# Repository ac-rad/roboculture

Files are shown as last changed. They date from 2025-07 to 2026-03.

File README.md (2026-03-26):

# RoboCulture



This repository accompanies the paper:

**RoboCulture: A Robotics Platform for Automated Biological Experimentation**  
Paper: https://arxiv.org/abs/2505.14941
Project website: https://ac-rad.github.io/roboculture

**RoboCulture** is a cost-effective and flexible platform
that uses a general-purpose robotic manipulator to automate
key biological tasks. RoboCulture performs liquid handling, interacts with lab equipment, and leverages computer vision
for real-time decisions using optical density-based growth
monitoring. 

This repository contains instructions to replicate our fully autonomous 15-hour yeast culture experiment where RoboCulture uses vision and force feedback and a modular behavior tree framework to robustly execute, monitor, and manage experiments.

## Repository Structure

```
roboculture/
├── digital-pipette-v2/    # Digital Pipette v2 hardware + software
├── cad-models/            # 3D-printable CAD assets for the yeast culture experiment
├── src/                   # ROS nodes and experiment code
│   ├── calibrate_camera.py              # Camera intrinsic calibration script
│   ├── process_well_data.py             # Generates growth curve plots from experiment CSVs
│   ├── camera_cal_imgs/             # Chessboard calibration images and calibration.npz
│   └── cell_culture/                # ROS package for the cell culture experiment
│       ├── action/                  # ROS action definitions (control, perception, imaging)
│       ├── cfg/                     # Dynamic reconfigure config files
│       ├── config/                  # ROS launch file and parameter config (config.yaml)
│       ├── msg/                     # ROS message definitions (PlateGrowthMsg)
│       └── src/                     # Python source code
│           ├── cc_control_node.py           # ROS node: robot motion and gripper control
│           ├── cc_perception_node.py        # ROS node: vision, AprilTag, well detection
│           ├── cell_culture_global_reconfigure.py  # Dynamic reconfigure server
│           ├── device_controller.py         # Serial device control (pipette, shaker)
│           ├── behaviour-tree/              # Behavior tree definitions for each experiment stage
│           ├── behaviour/                   # Individual behavior node implementations
│           ├── helpers/                     # Shared utilities
│           │   └── process_well_image.py    # Captures well images and logs HSV data to CSV
│           └── tools/
│               └── april_tag_offset_calibrator.py  # AprilTag pose offset calibration tool
├── data/                  # Experiment output (auto-created at runtime)
├── static/                # Project website files
├── FastSAM/               # FastSAM submodule
└── readme-imgs/           # Images used in this README
```

## Hardware and Materials

**Required Hardware and Scene Setup**
1. Digital Pipette v2  
   - Follow instructions in [`digital-pipette-v2/`](digital-pipette-v2/) to build the pipette
    - Connect Arduino to the workstation via USB-B
    - Connect the 6 V power supply
    - Attach the Digital Pipette via the three-wire connector
2. Intel RealSense D435i camera
      - Connect to the workstation using a USB-C cable supporting **USB 3.2**
3. Franka Emika robot with Robotiq 2F-85 gripper
4. OHAUS SHHD1619DG Heavy Duty Orbital Shaker Platform
    - Place the 96-well plate on top
    - Connect the shaker to the workstation via RS-232
5. 3D-printed pipette tip remover  
   - CAD: [`pipette_tip_remover_tag_tray_left.stl`](cad-models/pipette_tip_remover_tag_tray_left.stl)
   - Secure to the work table using base mounting holes
6. Biological waste bin
7. Falcon tube rack holding YPD media
8. 3D-printed pipette tip rack  
   - CAD: [`pipette_tip_rack_top_two_trays.stl`](cad-models/pipette_tip_rack_top_two_trays.stl)
   - Secure to the work table using base mounting holes
9. 96-well plate prepared with yeast  
   - Follow preparation protocol described in the paper

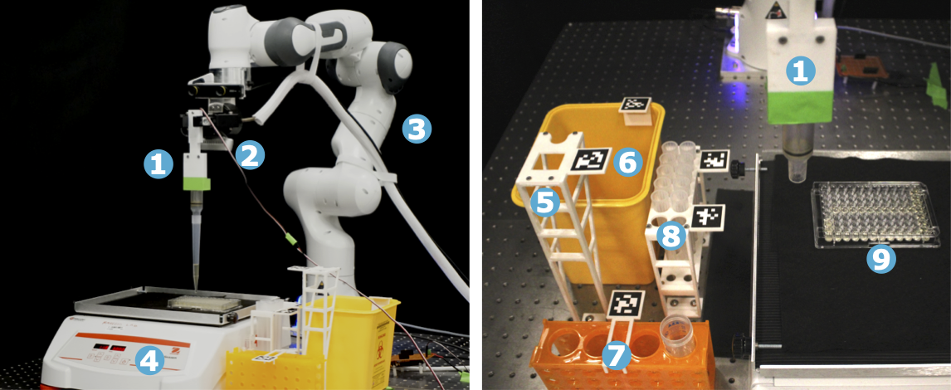
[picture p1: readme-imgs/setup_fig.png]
System setup


## Software Requirements

- **Operating system**: Ubuntu 20.04
- **ROS Version**: Noetic

## Setup

### 1) Clone the Repository

```bash
git clone --recurse-submodules https://github.com/ac-rad/roboculture.git
cd roboculture
```

---

### 2) Create and Activate the Python Environment

```bash
python -m venv roboculture
source roboculture/bin/activate
pip install -r requirements.txt
```

**FastSAM setup**
1. Download model weights from  
   https://github.com/CASIA-LMC-Lab/FastSAM#model-checkpoints
2. Create a `weights/` directory at the repo root
3. Place the model at:
   ```
   weights/FastSAM-x.pt
   ```

**FrankaPy**
- Follow installation instructions from:  
  https://github.com/iamlab-cmu/frankapy

---

### 3) Hardware Configuration

- Verify USB device IDs and serial ports: run `ls /dev/ttyUSB* /dev/ttyACM*` to list serial devices
- Confirm RealSense camera is operating
- Confirm RS-232 connection to the shaker

## Calibration

### Camera Calibration

1. Capture **10–15 chessboard images**
2. Place images in:
   ```
   src/camera_cal_imgs/
   ```
3. Run:
   ```bash
   python src/calibrate_camera.py
   ```
4. The generated calibration file will be saved to:
   ```
   src/camera_cal_imgs/calibration.npz
   ```

This is the path used by the perception node.

### Pipette Calibration
- Calibrate the Digital Pipette v2 as described in section 3.3 of [the original Digital Pipette paper](https://pubs.rsc.org/en/content/articlepdf/2023/dd/d3dd00115f)

## Data Processing

After running the experiment, well images and optical density measurements are saved to `data/well_growth_<timestamp>/well_growth.csv`.

To generate the growth curve figure (Fig. 9 in the paper), run the processing script from the repo root:

```bash
pip install pandas matplotlib numpy
python src/process_well_data.py
```

By default this reads all `well_growth.csv` files found under `../data/` and saves the outputs to `../output/`:
- `combined_data.csv` — merged data from all experiment runs
- `yeast_growth.pdf` — growth curves for all well groups
- `yeast_growth_30M_derivative.pdf` — derivative of the 30M group curve

**Custom paths**
```bash
python src/process_well_data.py --data-dir /path/to/data --output-dir /path/to/output
```

## Running the Experiment

### 1) Sample Preparation

From Section F of the paper:

> *Saccharomyces cerevisiae* was maintained on agarose plates containing 2% agarose in YPD broth at 4 °C under sterile conditions. Cell expansion, dilution, and plate preparation were performed as described in https://pubmed.ncbi.nlm.nih.gov/30320748/. Two identical 96-well plates were prepared: one for robotic handling and one for reference optical density measurements.

### 2) Launch the System

#### Camera (if using Docker, launch outside Docker)

```bash
roslaunch realsense2_camera rs_camera.launch \
  enable_depth:=false \
  color_width:=1920 \
  color_height:=1080 \
  color_fps:=30
```

---

#### Terminal Setup

> **Important:** Each node below requires a **new terminal window**. Run the following setup commands in each new terminal before launching a node:

```bash
docker exec -it <your_docker_env> bash
source ~/git/robotiq_ws/devel/setup.bash
cd roboculture/
source roboculture/bin/activate
source /opt/ros/noetic/setup.bash
source ~/git/frankapy/catkin_ws/devel/setup.bash
source devel/setup.bash
```

---

### 3) Launch Nodes (in order)

**Dynamic reconfigure**
```bash
rosrun cell_culture cell_culture_global_reconfigure.py
```

**Gripper controller**
```bash
cd ~/git/robotiq_ws/src/robot_interface/scripts/
python robotiq_dynamixel_runner.py
```

**Device controller**
```bash
python src/cell_culture/src/device_controller.py
```

**Control node**
```bash
rosrun cell_culture cc_control_node.py
```

**Perception node**
```bash
rosrun cell_culture cc_perception_node.py
```

**Behavior tree**
```bash
rosrun cell_culture experiment_btree.py
```

## Visualization Tools

Run these **outside Docker** in separate terminals.

Open dynamic reconfigure UI:
```bash
rosrun rqt_gui rqt_gui -s reconfigure
```
Open rviz to view camera outputs and image overlays for debugging:
```bash
rviz
```
Open behavior tree visualizer:
```bash
rosrun rqt_py_trees rqt_py_trees
```
Plot realtime well growth:
```bash
rqt_plot /cell_culture/plate_growth
```

---

## Troubleshooting

### RealSense USB Errors

**Symptoms**
- `Resource temporarily unavailable (Error 11)`
- `USB CAM overflow`
- Failure to launch at desired resolution

**Fix**
- Ensure the RealSense is connected via **USB 3.x**
- Replace the cable if necessary
- Verify USB type in the launch log

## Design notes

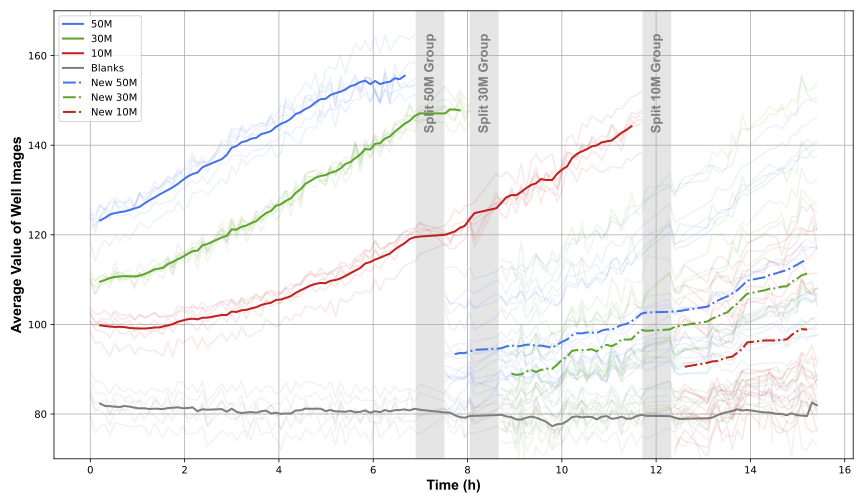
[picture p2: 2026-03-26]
static/images/yeast_growth.png

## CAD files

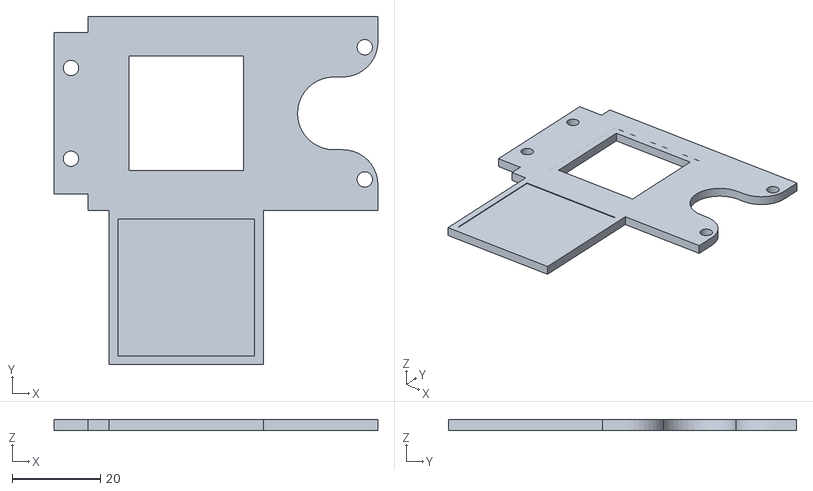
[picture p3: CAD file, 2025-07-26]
cad-models/pipette_tip_remover_tag_tray_left.stl
73.5 x 79.0 x 2.50

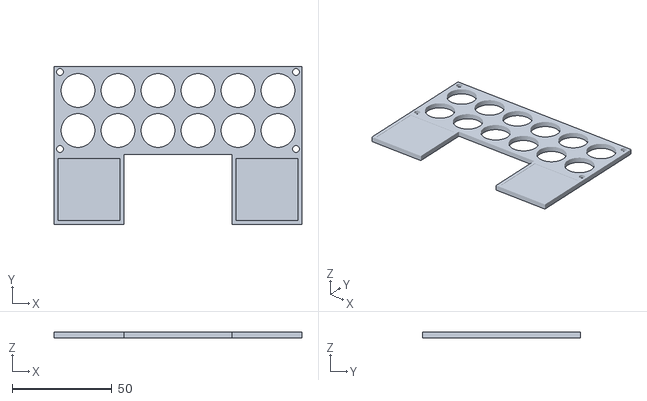
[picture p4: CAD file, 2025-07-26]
cad-models/pipette_tip_rack_top_two_trays.stl
124.0 x 79.0 x 3.00

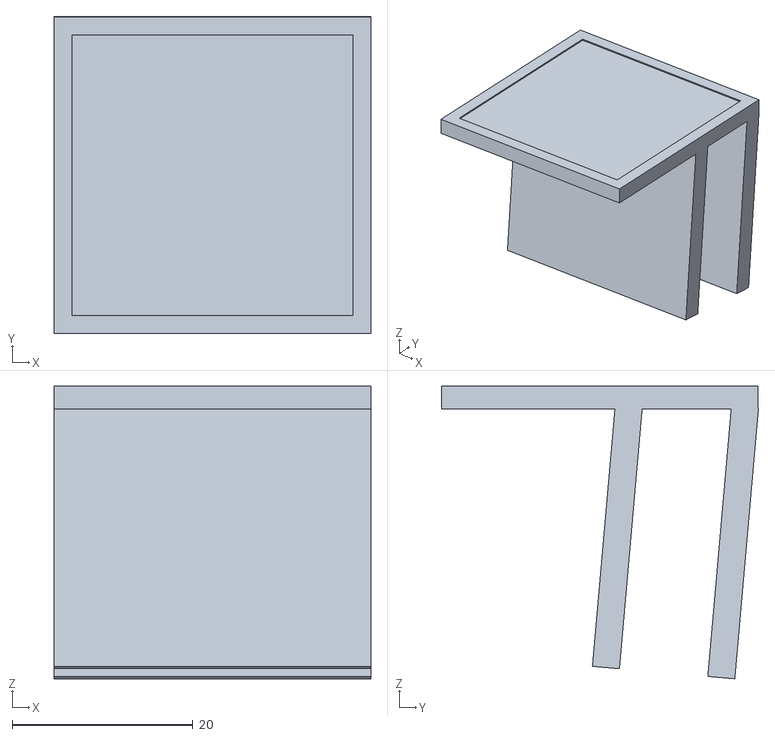
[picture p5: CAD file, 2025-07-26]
cad-models/waste_tag_holder.stl
35.0 x 35.0 x 32.3

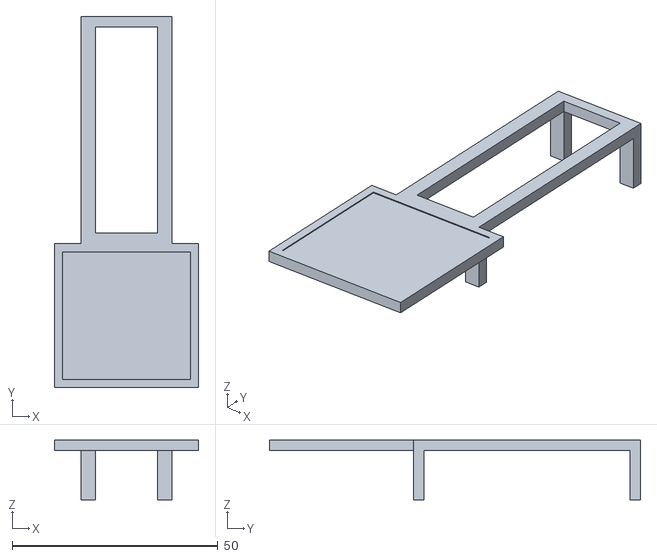
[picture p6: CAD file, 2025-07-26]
cad-models/media_rack_tag_holder.stl
35.0 x 90.2 x 14.5

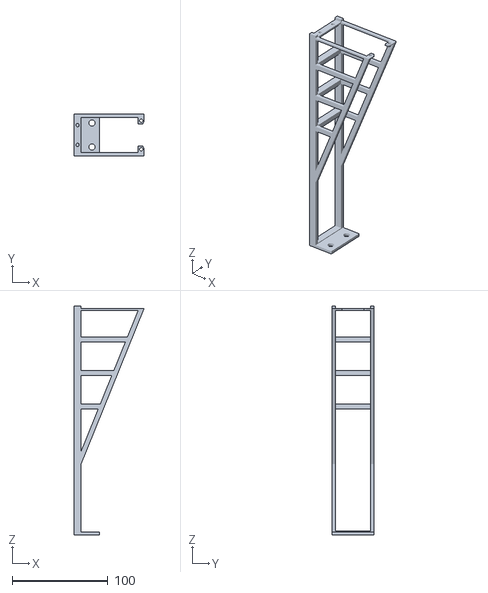
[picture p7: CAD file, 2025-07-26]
cad-models/tip_remover_stand.stl
73.5 x 44.0 x 239.4

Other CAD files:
cad-models/pipette_tip_remover_tag_tray_right.stl

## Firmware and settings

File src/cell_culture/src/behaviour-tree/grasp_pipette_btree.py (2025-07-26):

#!/usr/bin/env python

import functools
import operator
import py_trees
import py_trees_ros
import py_trees.console as console
import rospy
import sys
from sensor_msgs.msg import Image
from geometry_msgs.msg import Vector3
from std_msgs.msg import Bool
from cell_culture.src.behaviour.servo import Servo
from cell_culture.src.behaviour.close_gripper import CloseGripper
from cell_culture.src.behaviour.pose_servo import PoseServo
from cell_culture.src.behaviour.perceive import Perceive
from tip_rack_status import TipRackStatus
from cell_culture.src.behaviour.check_experiment_state import CheckExperimentState
from cell_culture.src.behaviour.set_experiment_state import SetExperimentState

class ToBlackboard(py_trees_ros.subscribers.ToBlackboard):
    """
    When ticking, updates with :attr:`~py_trees.common.Status.RUNNING` if it got no data,
    :attr:`~py_trees.common.Status.SUCCESS` otherwise.

    Blackboard Variables:
        - tag_found (:obj:`bool`): True if an april tag is found in the current image
        - holding_pipette (:obj:`bool`): True if the robot is holding the pipette
        - pipette_has_tip (:obj:`bool`): True if the pipette has a tip attached
        - pipette_has_media (:obj:`bool`): True if the pipette has media


    Args:
        name (:obj:`str`): name of the behaviour
        topic_name (:obj:`str`) : name of the ROS topic to listen to
        topic_type (:obj:`msg`) : type of the ROS message
        blackboard_variables (:obj:`dict`) : dictionary of blackboard variables to write to
    """
    def __init__(self, name, topic_name, topic_type, blackboard_variables):
        super(ToBlackboard, self).__init__(name=name,
                                           topic_name=topic_name,
                                           topic_type=topic_type,
                                           blackboard_variables=blackboard_variables,
                                           clearing_policy=py_trees.common.ClearingPolicy.ON_INITIALISE
                                           )
        self.blackboard = py_trees.blackboard.Blackboard()
        self.blackboard.perception_success = Bool()
        self.blackboard.force_low = Bool()
        self.blackboard.holding_pipette = Bool()
        self.blackboard.pipette_has_tip = Bool()
        self.blackboard.pipette_has_media = Bool()


    def update(self):
        """
        Call the parent to write the raw data to the blackboard
        """
        self.logger.debug("%s.update()" % self.__class__.__name__)
        status = super(ToBlackboard, self).update()
        if status != py_trees.common.Status.RUNNING:
            # we got something
            if type(self.blackboard.perception_success) is not bool:
                self.blackboard.perception_success = self.blackboard.perception_success.data

            if type(self.blackboard.force_low) is not bool:
                self.blackboard.force_low = self.blackboard.force_low.data

        return status


def create_root():

    # High level behaviours
    root = py_trees.composites.Parallel("GraspPipette (root)")
    topics2bb = py_trees.composites.Sequence("Topics2BB")
    # tag_found_2_bb = ToBlackboard(name="TagFound2BB", topic_name="/april_tag/found", topic_type=Bool, blackboard_variables={'tag_found': None})
    perception_success_2_bb = ToBlackboard(name="PerceptionSuccess2BB", topic_name="/cell_culture/perception/success", topic_type=Bool, blackboard_variables={'perception_success': None})
    ee_force_2_bb = ToBlackboard(name="EEForce2BB", topic_name="/cell_culture/control/ee_force", topic_type=Bool, blackboard_variables={'force_low': None})

    # Selectors
    grasp_pipette_selector = py_trees.composites.Selector("GraspPipette")
    attach_pipette_tip_selector = py_trees.composites.Selector("AttachPipetteTip")
    fill_media_selector = py_trees.composites.Selector("FillMedia")
    remove_pipette_tip_selector = py_trees.composites.Selector("RemovePipetteTip")
    pipette_well_selector = py_trees.composites.Selector("PipetteWell")

    # Sequences
    sequence = py_trees.composites.Sequence("Sequence")
    grasp_pipette_sequence = py_trees.composites.Sequence("GraspPipette")
    attach_pipette_tip_sequence = py_trees.composites.Sequence("AttachPipetteTip")
    fill_media_sequence = py_trees.composites.Sequence("FillMedia")
    remove_pipette_tip_sequence = py_trees.composites.Sequence("RemovePipetteTip")
    servo_to_april_tag1 = py_trees.composites.Sequence("ServoToAprilTag")
    servo_to_april_tag2 = py_trees.composites.Sequence("ServoToAprilTag")
    servo_to_april_tag3 = py_trees.composites.Sequence("ServoToAprilTag")

    # Blackboard variables
    # holding_pipette = py_trees.blackboard.CheckBlackboardVariable(name="HoldingPipette?", variable_name="holding_pipette", expected_value=True)
    holding_pipette = CheckExperimentState(name="check_holding_pipette", variable_to_check="holding_pipette", desired_value=True)
    # set_holding_pipette = py_trees.blackboard.SetBlackboardVariable(name="holding_pipette=True", variable_name="holding_pipette", variable_value=True)
    set_holding_pipette = SetExperimentState(name="set_holding_pipette", variable_to_set="holding_pipette", value=True)

    # pipette_has_tip = py_trees.blackboard.CheckBlackboardVariable(name="PipetteHasTip?", variable_name="pipette_has_tip", expected_value=True)
    # set_pipette_has_tip = py_trees.blackboard.SetBlackboardVariable(name="pipette_has_tip=True", variable_name="pipette_has_tip", variable_value=True)
    pipette_has_tip = CheckExperimentState(name="check_pipette_has_tip", variable_to_check="pipette_has_tip", desired_value=True)
    set_pipette_has_tip = SetExperimentState(name="set_pipette_has_tip", variable_to_set="pipette_has_tip", value=True)

    # pipette_has_no_tip = py_trees.blackboard.CheckBlackboardVariable(name="PipetteHasNoTip?", variable_name="pipette_has_tip", expected_value=False)
    # set_pipette_has_no_tip = py_trees.blackboard.SetBlackboardVariable(name="pipette_has_tip=False", variable_name="pipette_has_tip", variable_value=False)
    pipette_has_no_tip = CheckExperimentState(name="check_pipette_has_tip", variable_to_check="pipette_has_tip", desired_value=False)
    set_pipette_has_no_tip = SetExperimentState(name="set_pipette_has_tip", variable_to_set="pipette_has_tip", value=False)

    check_tip_rack_has_tips = CheckExperimentState(name="check_tip_rack_has_tips", variable_to_check="tip_rack_count", desired_value=0, operator=">", invert=False)
    decrement_tip_rack_count = SetExperimentState(name="decrement_tip_rack_count", variable_to_set="tip_rack_count", value="decrement")

    pipette_has_media = py_trees.blackboard.CheckBlackboardVariable(name="PipetteHasMedia?", variable_name="pipette_has_media", expected_value=True)
    set_pipette_has_media = py_trees.blackboard.SetBlackboardVariable(name="pipette_has_media=True", variable_name="pipette_has_media", variable_value=True)

    is_force_low = py_trees.blackboard.CheckBlackboardVariable(name="IsForceLow?", variable_name="force_low", expected_value=True)

    # Perception behaviours
    perceive_tag_3 = Perceive(name="Perceive", target='april_tag', num="3", offset=[48, 108.0, 0.0])
    perceive_tag_4 = Perceive(name="Perceive", target='april_tag', num="4", offset=[64.0, -104.0, 0.0])
    perceive_tag_6 = Perceive(name="Perceive", target='april_tag', num="6", offset=[60.0, -130.0, 0.0])
    perceive_tag_4_offset = Perceive(name="Perceive", target='april_tag', num="4", use_tip_offsets=True)

    # Robot control behaviours
    servo1 = Servo(name="Servo")
    servo2 = Servo(name="Servo", z="0.40", kp_z=0.01)
    servo3 = Servo(name="Servo")
    # servo_to_tip = Servo(name="Servo", z="0.360", kp_z=0.004, kp_img=0.000005, sleep=0)
    servo_to_tip = Servo(name="Servo", z="0.36", kp_z=0.004, kp_img=0.000005, sleep=0)

    close_gripper = CloseGripper(name="CloseGripper")

    ps_approach_pipette = PoseServo(name="PS", x="~", y="~", z="0.368") # add 0.055 for custom gripper config
    ps_grasp_pipette = PoseServo(name="PS", x="~0.042", y="~", z="~") # Relative: move 0.05m in x direction
    ps_raise_pipette = PoseServo(name="PS", x="~", y="~", z="~0.16")
    
    ps_lower_into_beaker = PoseServo(name="PS", x="~", y="~", z="~-0.28")
    ps_raise_out_of_beaker = PoseServo(name="PS", x="~", y="~", z="~0.28", sleep=1)

    ps_return_to_init_pose = PoseServo(name="PS", x="0.24", y="0.066", z="0.594")
    ps_return_to_init_pose2 = PoseServo(name="PS", x="0.24", y="0.066", z="0.594")
    ps_return_to_init_pose3 = PoseServo(name="PS", x="0.24", y="0.066", z="0.594")
    # ps_return_to_init_pose2 = PoseServo(name="PS", x="0.1902", y="0.1163", z="0.5737")

    spiral = Servo(name="Spiral", spiral=True)
    ps_lower_into_tip = PoseServo(name="PS", x="~", y="~", z="~-0.029", kp=0.0037)
    ps_raise_out_of_tip = PoseServo(name="PS", x="~", y="~", z="~0.25")

    # save_image = Perceive(name="SaveImage", target="april_tag", num="save_image")

    ps_lower_to_remover = PoseServo(name="PS", x="~", y="~", z="0.415")
    ps_into_remover = PoseServo(name="PS", x="~0.07", y="~", z="~")
    ps_lift_and_detach = PoseServo(name="PS", x="~", y="~", z="~0.15")

    # tip_rack_status = TipRackStatus(name="TipRackStatus")


    # Idle
    idle1 = py_trees.behaviours.Running(name="Idle")
    idle2 = py_trees.behaviours.Running(name="Idle")
    idle3 = py_trees.behaviours.Running(name="Idle")
    idle4 = py_trees.behaviours.Running(name="Idle")
    fail = py_trees.behaviours.Failure(name="Fail")

    ### Construct tree ###
    root.add_children([topics2bb, sequence])
    topics2bb.add_children([perception_success_2_bb, ee_force_2_bb])
    sequence.add_children([grasp_pipette_selector, attach_pipette_tip_selector, remove_pipette_tip_selector])
    # sequence.add_children([grasp_pipette_selector, attach_pipette_tip_selector])

    servo_to_april_tag1.add_children([perceive_tag_3, servo1])
    servo_to_april_tag2.add_children([perceive_tag_4, servo2])
    servo_to_april_tag3.add_children([perceive_tag_6, servo3])

    grasp_pipette_sequence.add_children([servo_to_april_tag1, ps_approach_pipette, ps_grasp_pipette, close_gripper, ps_raise_pipette, ps_return_to_init_pose, set_holding_pipette])
    grasp_pipette_selector.add_children([holding_pipette, grasp_pipette_sequence])

    # attach_pipette_tip_sequence.add_children([tip_rack_status, servo_to_april_tag2, ps_pipette_attach_height, perceive_tip, servo_to_tip, spiral, ps_lower_into_tip, ps_raise_out_of_tip, set_pipette_has_tip])
    attach_pipette_tip_sequence.add_children([check_tip_rack_has_tips, servo_to_april_tag2, perceive_tag_4_offset, servo_to_tip, spiral, ps_lower_into_tip, ps_raise_out_of_tip, ps_return_to_init_pose2, set_pipette_has_tip, decrement_tip_rack_count])
    attach_pipette_tip_selector.add_children([pipette_has_tip, attach_pipette_tip_sequence])

    remove_pipette_tip_sequence.add_children([servo_to_april_tag3, ps_lower_to_remover, ps_into_remover, ps_lift_and_detach, ps_return_to_init_pose3, set_pipette_has_no_tip])
    remove_pipette_tip_selector.add_children([pipette_has_no_tip, remove_pipette_tip_sequence])

    return root


def shutdown(behaviour_tree):
    behaviour_tree.interrupt()


def main():
    rospy.loginfo("Tree")
    rospy.init_node("tree")
    root = create_root()
    behaviour_tree = py_trees_ros.trees.BehaviourTree(root)
    rospy.on_shutdown(functools.partial(shutdown, behaviour_tree))
    if not behaviour_tree.setup(timeout=15):
        console.logerror("failed to setup the tree, aborting.")
        sys.exit(1)
    behaviour_tree.tick_tock(30) # 10x a second

if __name__ == '__main__':
    main()

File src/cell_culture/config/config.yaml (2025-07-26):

# config.yaml
perception:
  model_path: "./weights/FastSAM-x.pt" # Path to FastSAM weights
  perception_method: "edge" # edge or april_tag
  plate_prompt: "microplate" # microplate
  preprocess_image: True
  desired_well: 0 # Desired well to move to. 0 is top left, 7 is bottom left, 88 is top right, 95 is bottom right
  using_kalman_filter: False # True = Use Kalman filter to smooth trajectory
  using_well_monitoring: False # True = Track images of wells for detecting contents over time
  prompt_points: [[443, 20], [419, 99]] # Prompt points to use for pipette segmentation. If `[]`: a window will pop up to select them.


control:
  rate: 500 # Rate of control loop in Hz
  kp: 0.0007 # Proportional gain for PID controller (np.eye(2) * kp)
  kd: 0.00001 # Derivative gain for PID controller (np.eye(2) * kd)
  ki: 0.00001 # Integral gain for PID controller (np.eye(2) * ki)
  target_z: 0.504 # Target z position for pipette tip (panda_link_0 -> panda_hand) : 0.409 on table, 0.504 on scale
  init_pose_media: [ 0.41202604, -0.18653185,  0.38743793] # Starting pose relative to reset pose (franka_tool to world) (x, y, z) [ 0.41202604 -0.18653185  0.38743793]
  init_pose_plate: [0.46041651, 0.10101492, 0.42765366] # Starting pose relative to reset pose (franka_tool to world) (x, y, z) : [0.2, 0, -0.15] [0.46041651 0.10101492 0.42765366]
  lower_into_media_dist: 0.085 # Distance to lower pipette into media
  lower_height: 0.01 # Amount to lower pipette tip for insertion
  
  translational_stiffnesses: [3000.0, 2000.0, 1000.0] # Stiffnesses for translational directions (x, y, z)
  rotational_stiffnesses: [100.0,100.0,50.0] 

pipette:  
  pipette_port: "/dev/ttyACM1"
  pipette_extended: 1850
  pipette_retracted: 1300
  pipette_increment: 15

plate:
  plate_type: 96 # 96, 24, 6
  plate_dist: [9.1, 19.2, 38.67] # Distance between centers of wells in each well plate [96, 24, 6] (mm)
  plate_left_offset: [14.3, 14.7, 24.8] # Distance from left edge to center of first column in each well plate [96, 24, 6] (mm)
  plate_up_offset: [11.36, 14.1, 22.32] # Distance from top edge to center of first row in 96 well plate [96, 24, 6] (mm)

  plate_length: 127.89 # Length of well plate in mm
  plate_width: 85.50 # Width of well plate in mm


global_parameters:
  with_robot: True # True = Using Franka robot
  live_inference: True # True = Live inference (using webcam), False = inference on video (defined by video_name)
  
  using_pipette: True
  using_pipette_liquid: False
  using_scale: False
  using_shaker: False
  is_aspiration: False # True = Aspiration, False = Dispense

  classification_dataset_mode: False
  center_cam_coord: [320, 300]

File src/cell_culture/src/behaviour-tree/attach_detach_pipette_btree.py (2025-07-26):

#!/usr/bin/env python

import functools
import operator
import py_trees
import py_trees_ros
import py_trees.console as console
import rospy
import sys
from sensor_msgs.msg import Image
from geometry_msgs.msg import Vector3
from std_msgs.msg import Bool
from behaviour.servo import Servo
from behaviour.close_gripper import CloseGripper
from behaviour.pose_servo import PoseServo
from behaviour.perceive import Perceive
from behaviour.check_experiment_state import CheckExperimentState
from behaviour.set_experiment_state import SetExperimentState

class ToBlackboard(py_trees_ros.subscribers.ToBlackboard):

    def __init__(self, name, topic_name, topic_type, blackboard_variables):
        super(ToBlackboard, self).__init__(name=name,
                                           topic_name=topic_name,
                                           topic_type=topic_type,
                                           blackboard_variables=blackboard_variables,
                                           clearing_policy=py_trees.common.ClearingPolicy.ON_INITIALISE
                                           )
        self.blackboard = py_trees.blackboard.Blackboard()
        self.blackboard.perception_success = Bool()
        self.blackboard.holding_pipette = Bool()
        self.blackboard.pipette_has_tip = Bool()
        self.blackboard.pipette_has_media = Bool()
        self.blackboard.tip_coords_found = Bool()


    def update(self):
        """
        Call the parent to write the raw data to the blackboard
        """
        self.logger.debug("%s.update()" % self.__class__.__name__)
        status = super(ToBlackboard, self).update()
        if status != py_trees.common.Status.RUNNING:
            # we got something
            if type(self.blackboard.perception_success) is not bool:
                self.blackboard.perception_success = self.blackboard.perception_success.data

        return status


def create_root():
    # behaviours
    root = py_trees.composites.Parallel("(root)")
    topics2bb = py_trees.composites.Sequence("Topics2BB")
    perception_success_2_bb = ToBlackboard(name="PerceptionSuccess2BB", topic_name="/cell_culture/perception/success", topic_type=Bool, blackboard_variables={'perception_success': None})
    ee_force_2_bb = ToBlackboard(name="EEForce2BB", topic_name="/cell_culture/control/ee_force", topic_type=Bool, blackboard_variables={'force_low': None})
    
    tasks = py_trees.composites.Sequence("Tasks")
    
    #### 1. Grasp Pipette
    grasp_pipette_sel = py_trees.composites.Selector("GraspPipette")
    grasp_pipette_seq = py_trees.composites.Sequence("GraspPipette")
    servo_to_april_tag_14 = py_trees.composites.Sequence("ServoToAprilTag")

    holding_pipette = CheckExperimentState(name="check_holding_pipette", variable_to_check="holding_pipette", desired_value=True)
    set_holding_pipette = SetExperimentState(name="set_holding_pipette", variable_to_set="holding_pipette", value=True)
    
    perceive_tag_14 = Perceive(name="PerceiveTag3", target="april_tag", num="14", offset=[-108, 252.0, 0.0])
    servo_tag_14 = Servo(name="ServoTag14")

    ps_approach_pipette = PoseServo(name="PS", x="~", y="~", z="0.372")
    ps_grasp_pipette = PoseServo(name="PS", x="~0.073", y="~0.04", z="~")
    ps_raise_pipette = PoseServo(name="PS", x="~", y="~", z="~0.16")
    close_gripper = CloseGripper(name="CloseGripper")
    ps_return_to_init_pose = PoseServo(name="PS", x="0.29012432", y="0.1168218", z="0.5939036")
    ps_return_to_init_pose1 = PoseServo(name="PS", x="0.29012432", y="0.1168218", z="0.5939036")
    ps_return_to_init_pose2 = PoseServo(name="PS", x="0.29012432", y="0.1168218", z="0.5939036")
    ps_return_to_init_pose3 = PoseServo(name="PS", x="0.29012432", y="0.1168218", z="0.5939036")
    ps_return_to_init_pose4 = PoseServo(name="PS", x="0.28012432", y="0.1068218", z="0.5939036")
    ps_return_to_init_pose5 = PoseServo(name="PS", x="0.29012432", y="0.1168218", z="0.5939036")


    #### 2. Attach Pipette Tip
    attach_pipette_tip_sel = py_trees.composites.Selector("AttachPipetteTip")
    attach_pipette_tip_seq = py_trees.composites.Sequence("AttachPipetteTip")
    servo_to_april_tag_4 = py_trees.composites.Sequence("ServoToAprilTag")

    pipette_has_tip = CheckExperimentState(name="check_pipette_has_tip", variable_to_check="pipette_status", desired_value=0, invert=True)
    set_pipette_has_tip = SetExperimentState(name="set_pipette_has_tip", variable_to_set="pipette_status", value=1)
    set_pipette_has_no_tip = SetExperimentState(name="set_pipette_has_no_tip", variable_to_set="pipette_status", value=0)
    check_tip_rack_has_tips = CheckExperimentState(name="check_tip_rack_has_tips", variable_to_check="tip_rack_count", desired_value=0, operator=">", invert=False)
    decrement_tip_rack_count = SetExperimentState(name="decrement_tip_rack_count", variable_to_set="tip_rack_count", value="decrement")

    spiral = Servo(name="Spiral", spiral=True)

    perceive_tag_4 = Perceive(name="Perceive", target='april_tag', num="4", offset=[8.0, -130.0, 0.0])
    perceive_tag_4_offset = Perceive(name="Perceive", target='april_tag', num="4", use_tip_offsets=True)

    servo_tag_4 = Servo(name="Servo", z="0.385", kp_z=0.01)
    servo_tag_4_offset = Servo(name="Servo", z="0.357", kp_z=0.006, kp_img=0.000005, sleep=0)

    ps_lower_into_tip = PoseServo(name="PS", x="~", y="~", z="~-0.029", kp=0.0037)
    ps_raise_out_of_tip = PoseServo(name="PS", x="~", y="~", z="~0.25")
    set_pipette_expel = SetExperimentState(name="set_pipette_expel", variable_to_set="pipette_actuator_pos", value=1850)

    # perceive_tip = Perceive(name="Perceive", target='tip', num="")

    #### 3. Remove pipette tip
    remove_pipette_tip_sel = py_trees.composites.Selector("RemovePipetteTip")
    remove_pipette_tip_seq = py_trees.composites.Sequence("RemovePipetteTip")
    servo_to_april_tag_6 = py_trees.composites.Sequence("ServoToAprilTag")
    servo_to_april_tag_3_2 = py_trees.composites.Sequence("ServoToAprilTag") 
    perceive_tag_6 = Perceive(name="Perceive", target='april_tag', num="6", offset=[20, -224.0, 0.0])
    # perceive_tag_3_2 = Perceive(name="Perceive", target='april_tag', num="3", offset=[-18.0, 300, 0.0]) 
    servo_tag_6 = Servo(name="ServoTag6")
    # servo_tag_3_2 = Servo(name="ServoTag6")
    ps_lower_to_remover = PoseServo(name="PS", x="~", y="~", z="0.415")
    ps_into_remover = PoseServo(name="PS", x="~0.055", y="~", z="~", kp=0.006)
    ps_lift_and_detach = PoseServo(name="PS", x="~", y="~", z="~0.15", kp=0.006)
    # use tag on tip remover (3) to make final alignement since it is fixed. 
    # use tag on waste bin (6) to make initial alignment since tag on tip remover will be blocked by pipette tip

    # tree
    root.add_children([topics2bb, tasks])
    topics2bb.add_children([perception_success_2_bb])

    # Global selector (all tasks)
    tasks.add_children([grasp_pipette_sel, attach_pipette_tip_sel, remove_pipette_tip_sel])
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

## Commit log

2025-07-09 Add digital pipette v2 files and instructions
    [dpv2_cover.f3d, dpv2_cover.stl, dpv2_platform.f3d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]
2025-07-26 Add roboculture src files
    [cell_culture_global.cfg, cell_culture_perception.cfg]
2025-07-26 Add stl files
    [media_rack_tag_holder.stl, pipette_tip_rack_top_two_trays.stl, pipette_tip_remover_tag_tray_left.stl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]
2025-10-17 replace digital pipette folder with submodule
    [dpv2_cover.f3d, dpv2_cover.stl, dpv2_platform.f3d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]
2026-03-26 Update readme, add data zip, clean up process well data script
    [roboculture-combined-well-data-aug28.csv]
